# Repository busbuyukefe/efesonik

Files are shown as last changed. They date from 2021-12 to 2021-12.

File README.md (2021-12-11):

# efesonik (v2)

A directional soundbar proof-of-concept using cheap 40kHz transducers.

This project can work with the code from [gururise](https://github.com/gururise/directional_speaker) and uses the STM32-bluepill library of [yet-another-average-joe](https://github.com/yet-another-average-joe/Kicad-STM32)

On the [PDF](https://github.com/busbuyukefe/efesonik/blob/main/Parametrik%20Hoparl%C3%B6r.pdf) you can find my notes about the price, working principle and things like layout of the transducers I took while planning/designing the project.

This system has a set of parametric-speaker arranged side-by-side with independent angle control for each one. This allows the system to be focused on more than one targets thus making a more usable. With each section being able to rotate independently it takes less space with the rotating-mechanism than a single speaker with a gimbal.

You can see the code I used in this [gist](https://gist.github.com/busbuyukefe/7ff0d10a8e1e2d5ed5e22a36067409bf) I posted quite a while ago (Which is essentialy the same code from gururise but with a different pinout)

In the amp section of the block diagram you can use anything else to handle the switching. 
The KiCAD drawing has a single sided PCB design but I didn't had the time to check if it is working.

## I sold this project to someone around March of 2021 so I no longer have it.

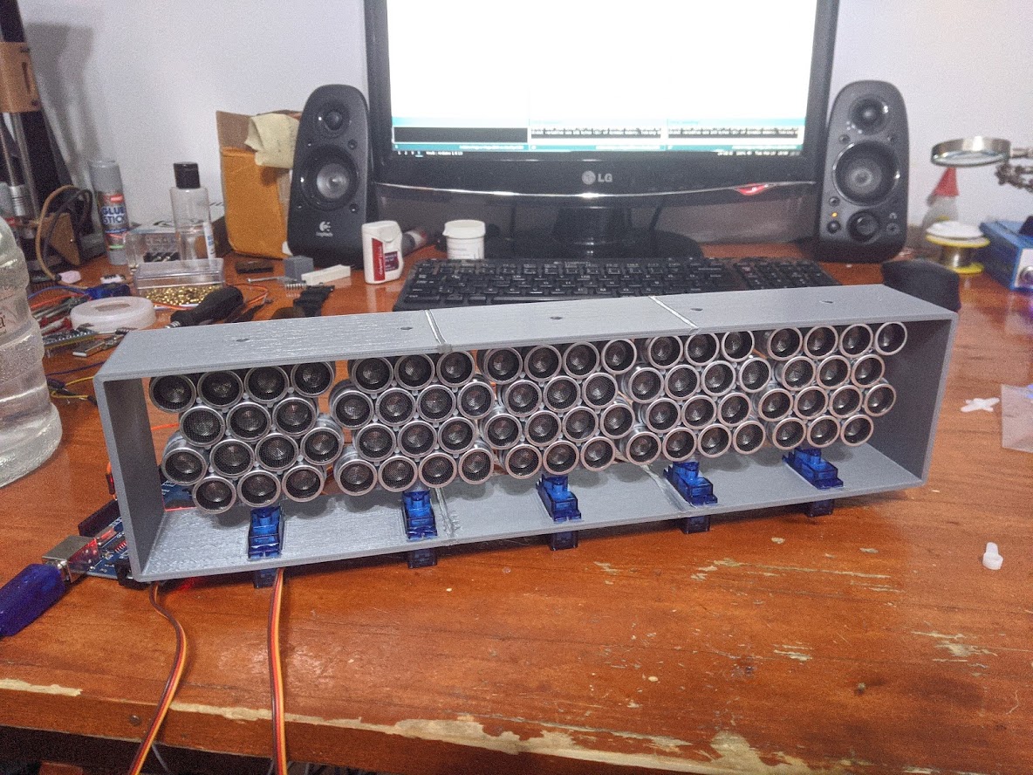
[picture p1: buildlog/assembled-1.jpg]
Assembled Project

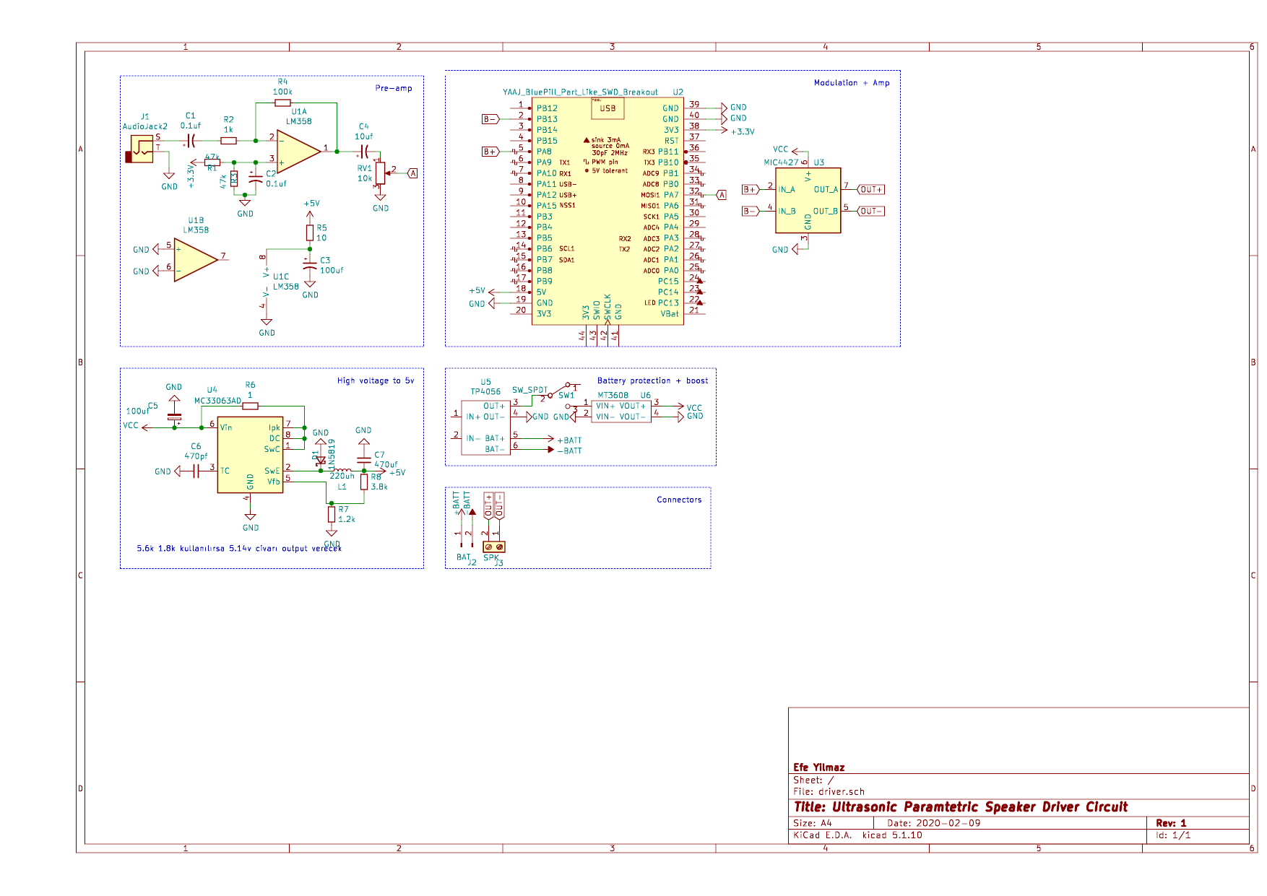
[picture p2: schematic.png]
Schematic of the driver


Video of the first test with the STM32 driver using an old parametric array I built:
first test (https://www.youtube.com/watch?v=-BTZwW2fiP0)

Some photos I took during building it:

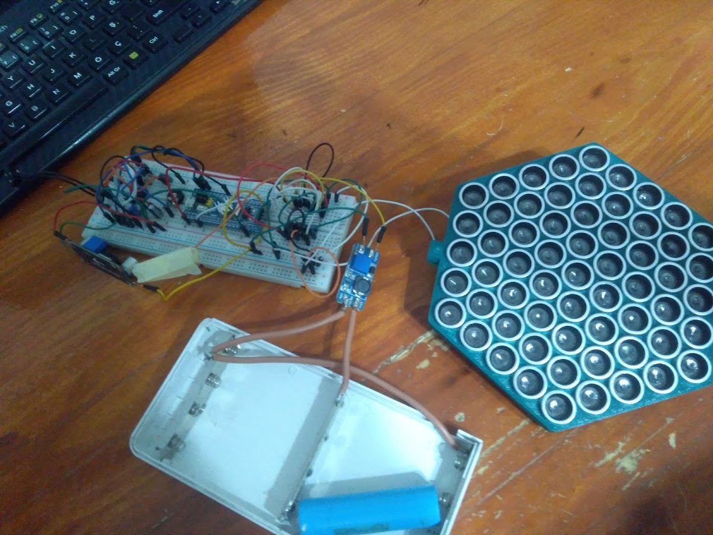
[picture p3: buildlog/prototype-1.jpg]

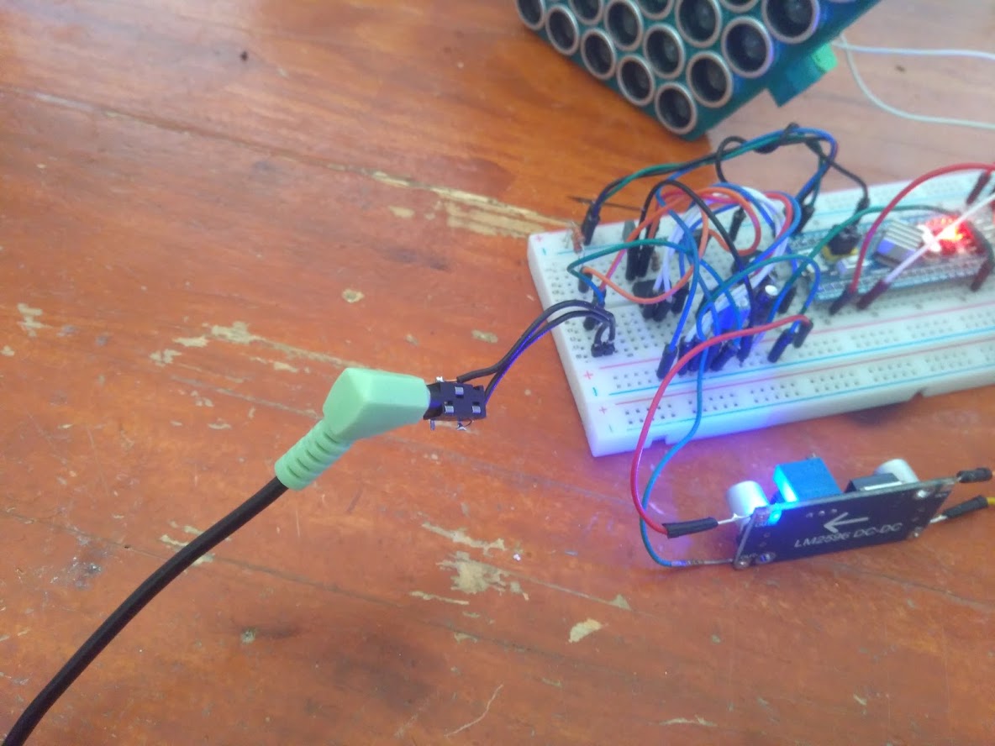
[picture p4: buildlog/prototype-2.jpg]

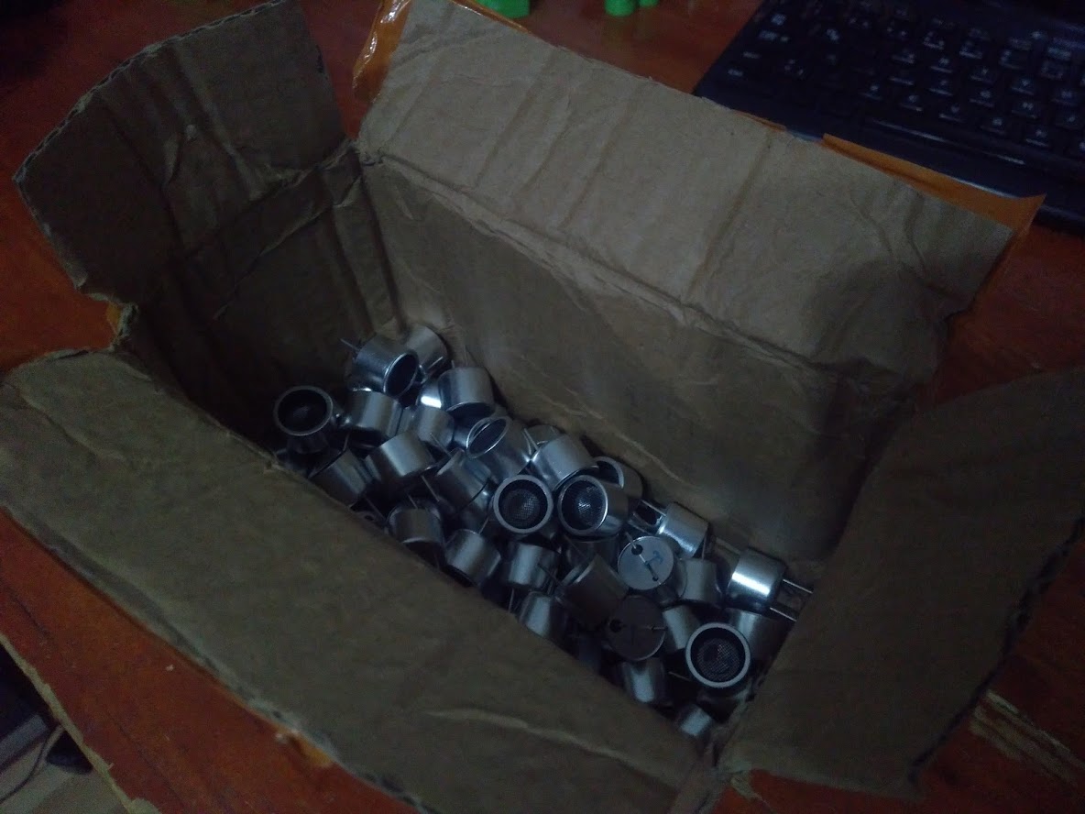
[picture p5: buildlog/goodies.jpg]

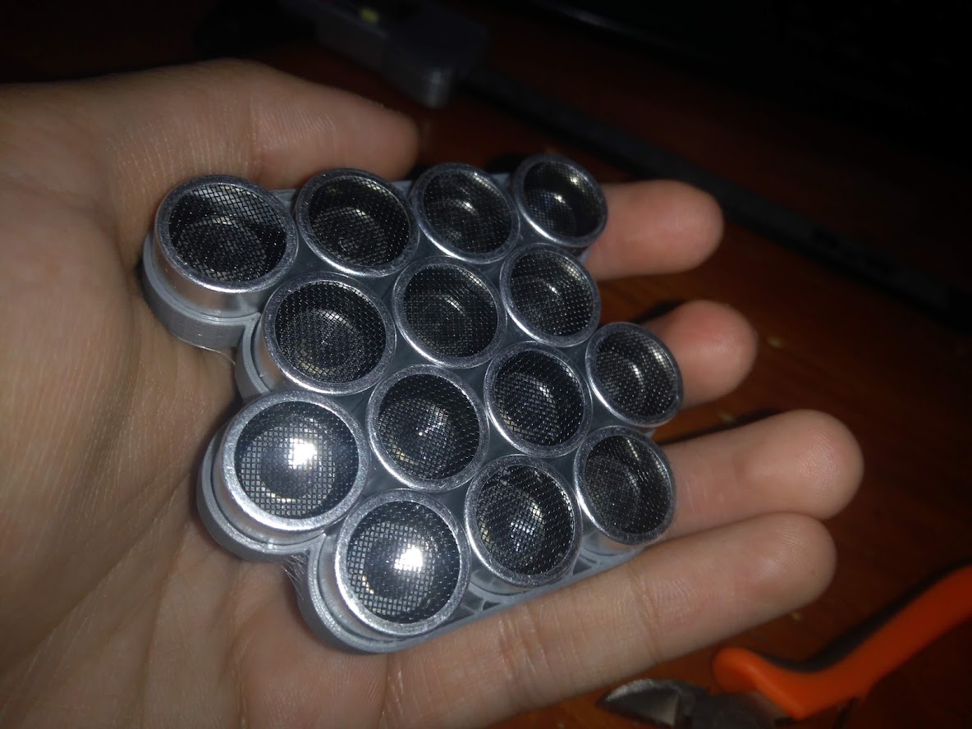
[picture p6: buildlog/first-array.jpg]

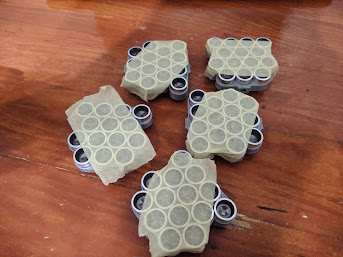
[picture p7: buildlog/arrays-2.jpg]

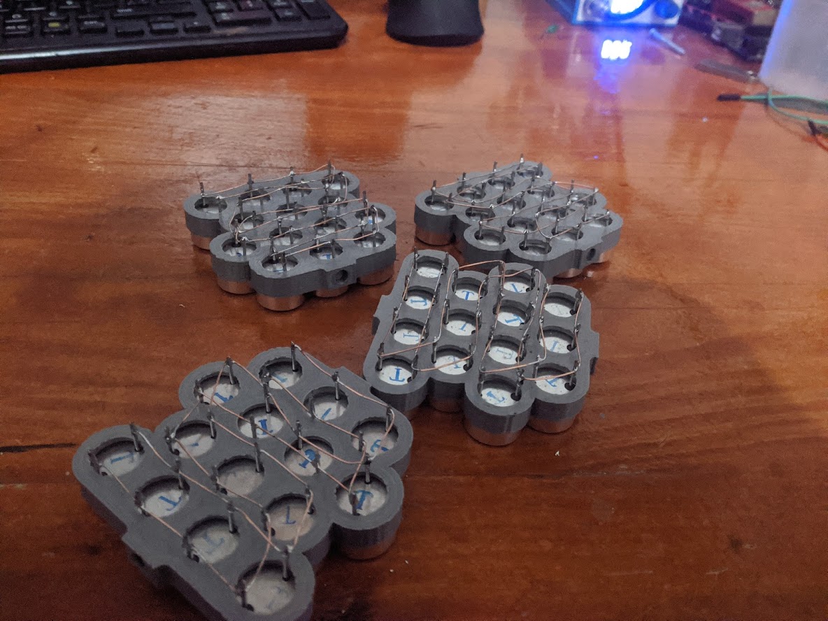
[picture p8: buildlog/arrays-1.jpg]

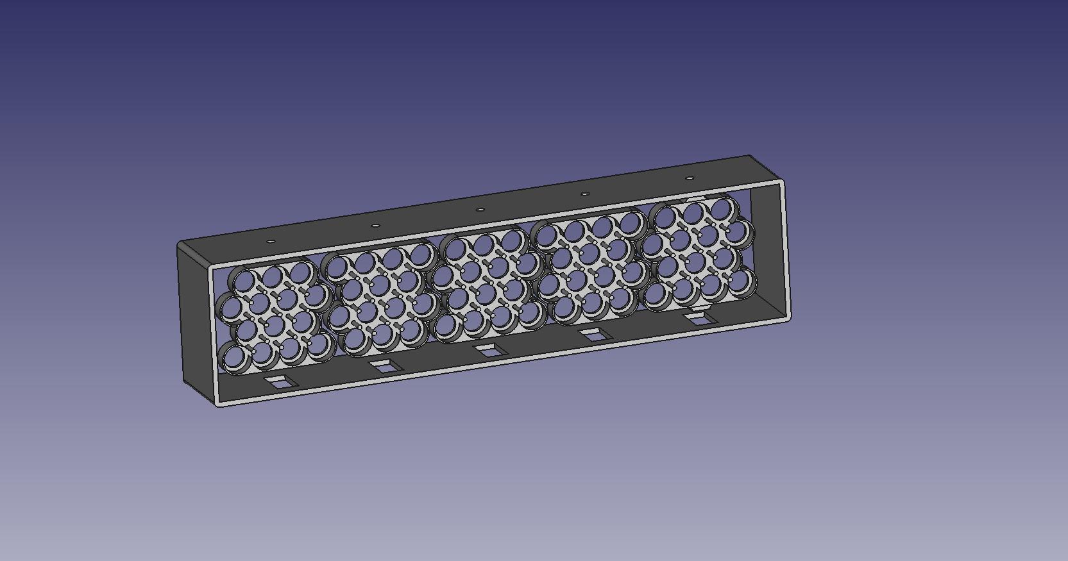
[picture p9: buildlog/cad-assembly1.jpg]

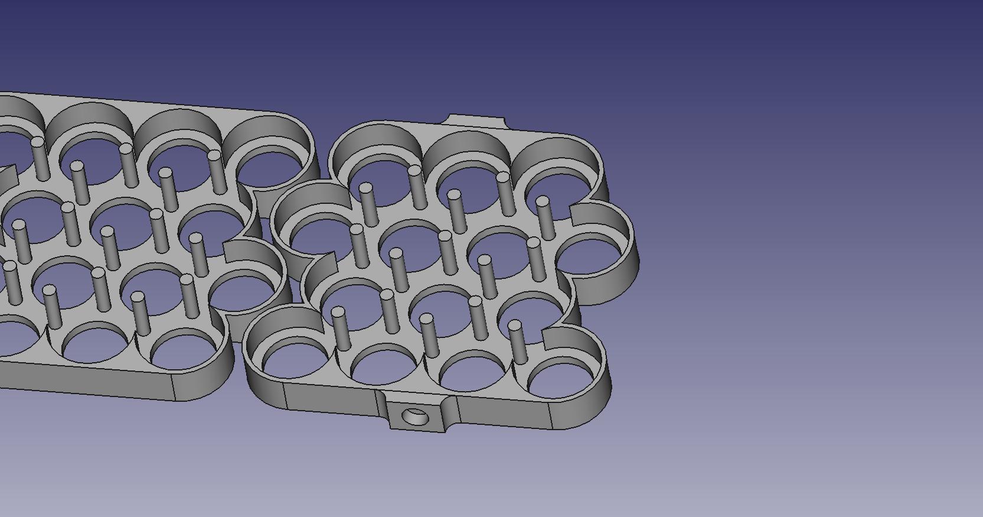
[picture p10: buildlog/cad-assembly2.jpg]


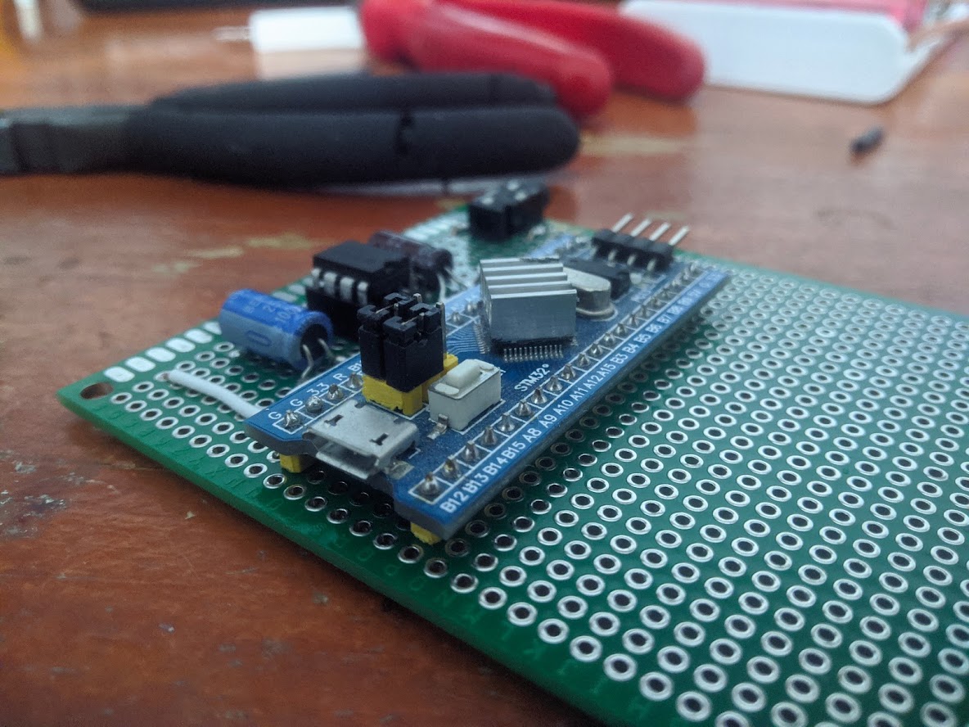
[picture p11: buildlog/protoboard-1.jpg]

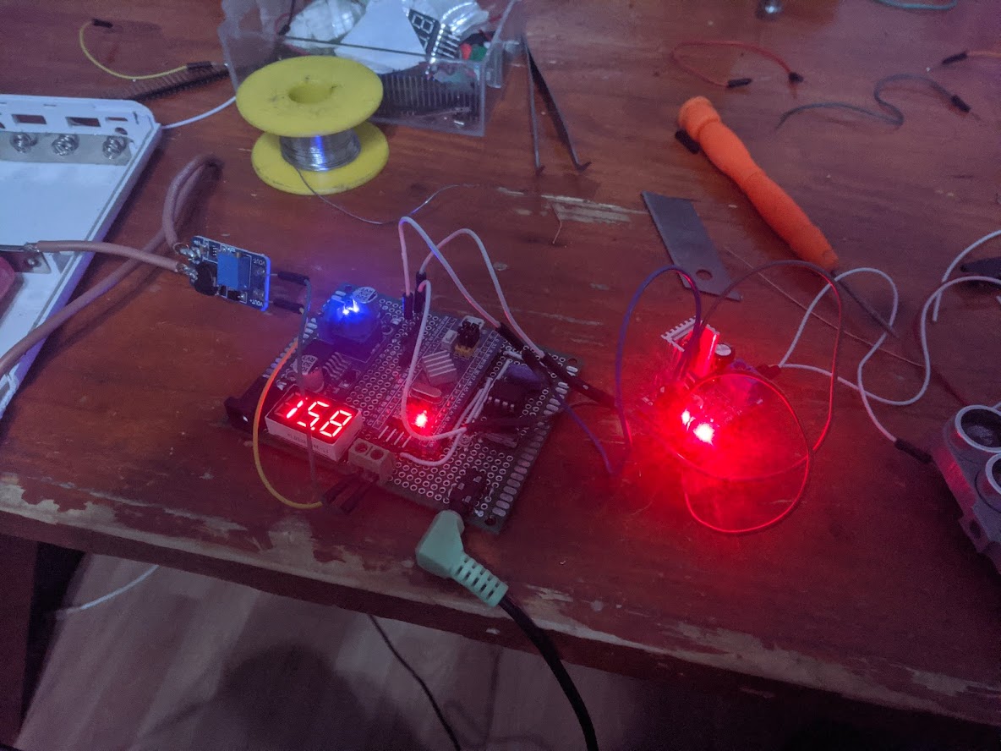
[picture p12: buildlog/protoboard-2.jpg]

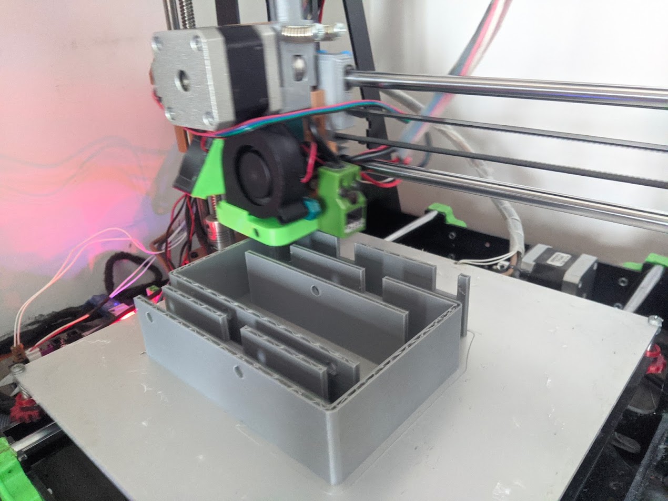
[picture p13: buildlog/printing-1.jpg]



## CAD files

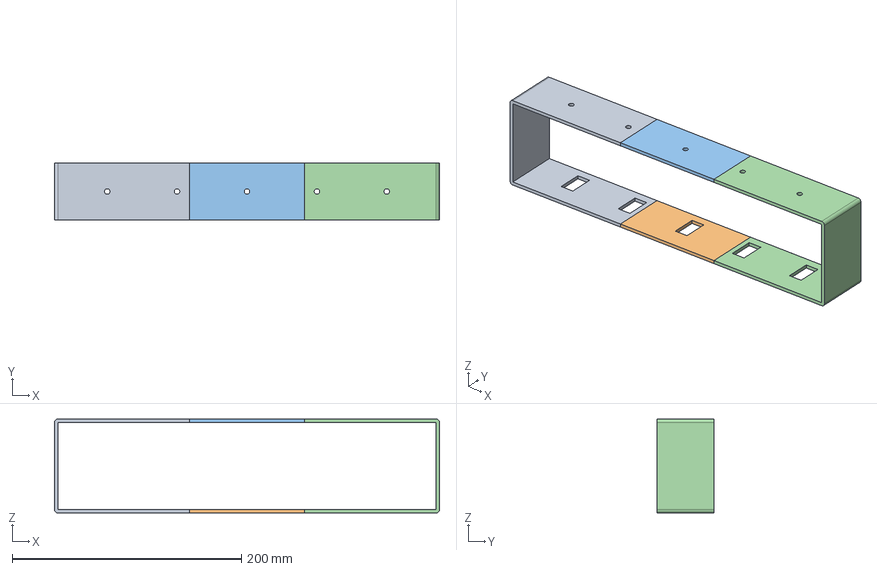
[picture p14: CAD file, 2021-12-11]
3d/frame.FCStd
336.0 x 50.0 x 82.0 mm
Slice.0
Slice.1
Slice.2
Slice.3

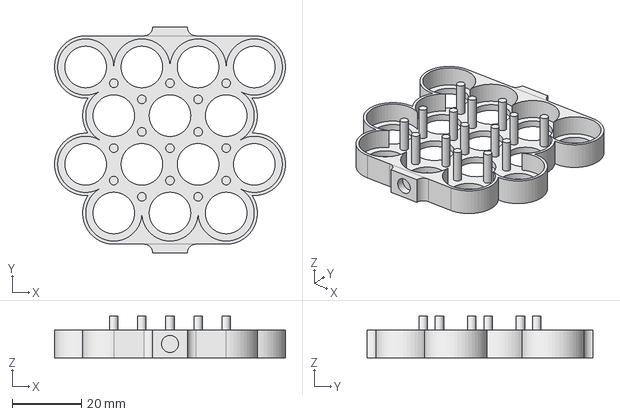
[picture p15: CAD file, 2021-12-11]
3d/test.FCStd
66.6 x 65.1 x 12.0 mm

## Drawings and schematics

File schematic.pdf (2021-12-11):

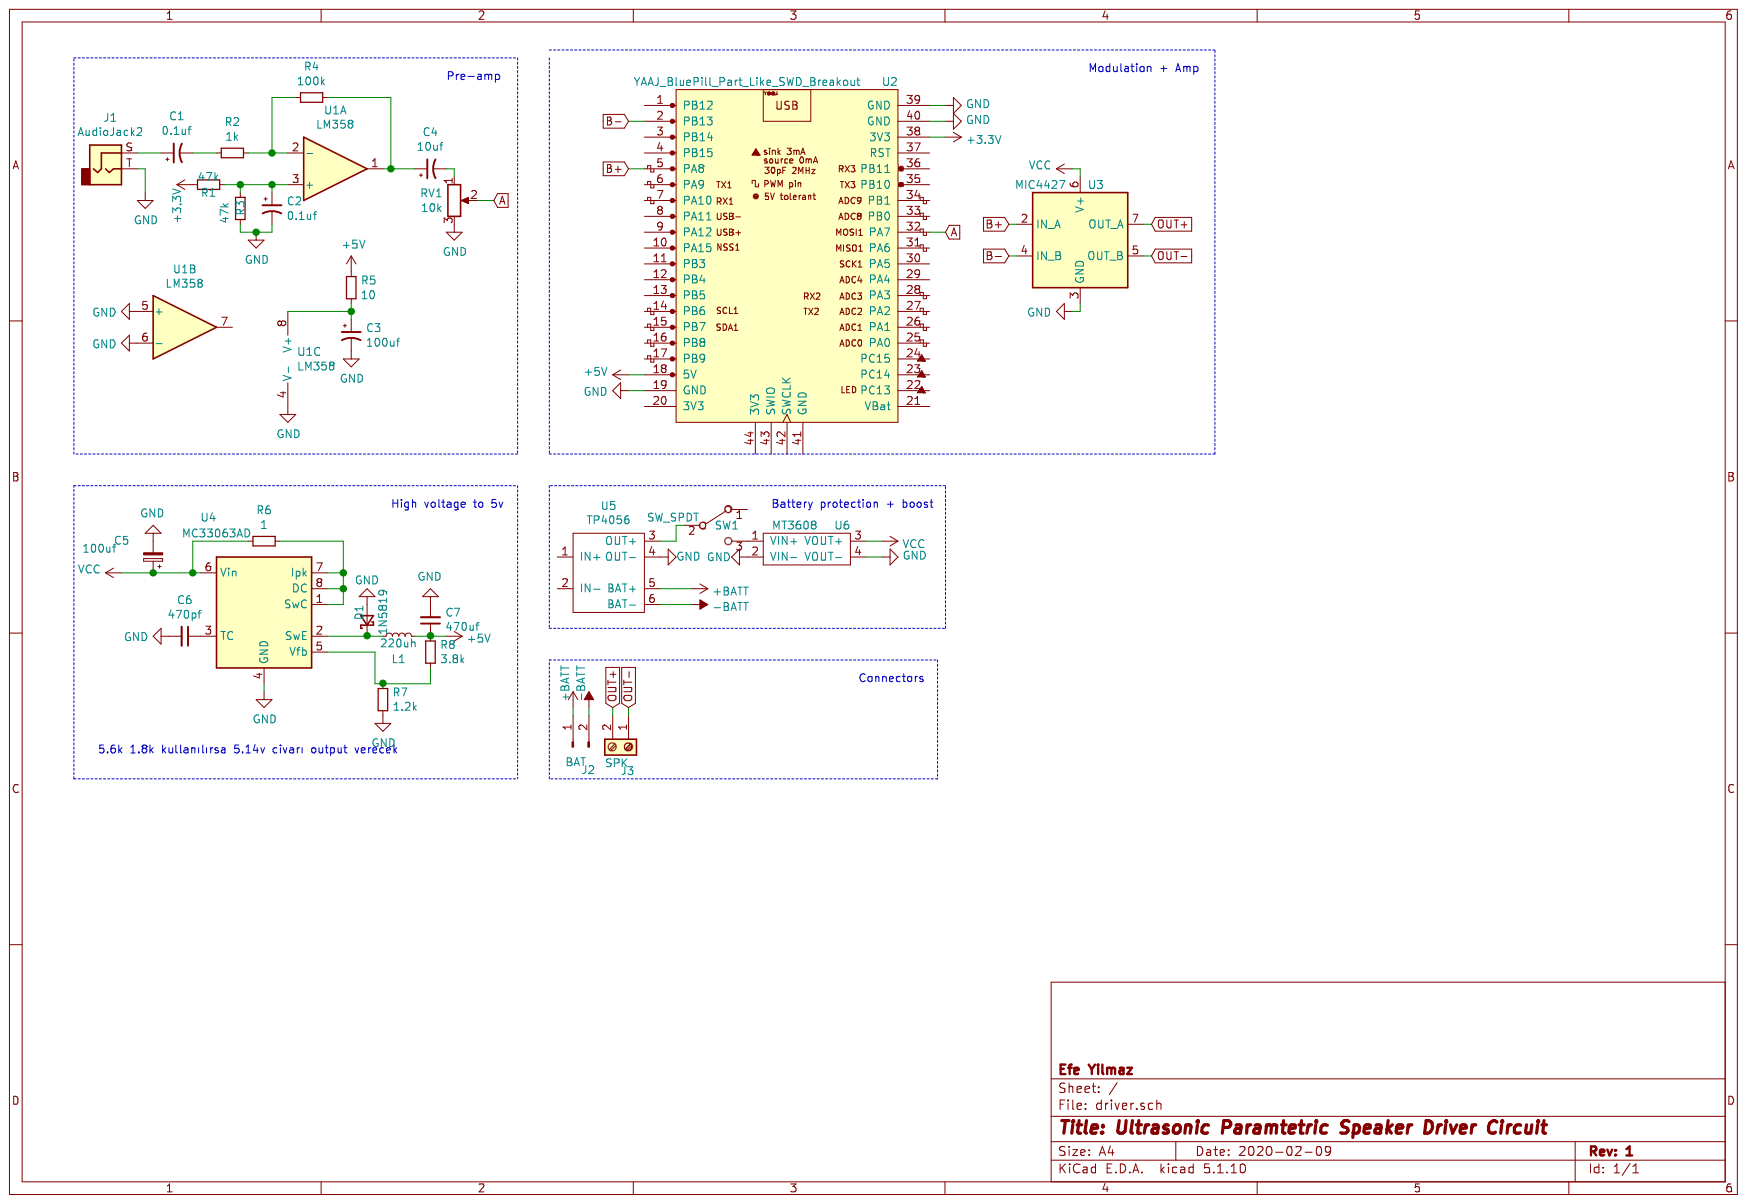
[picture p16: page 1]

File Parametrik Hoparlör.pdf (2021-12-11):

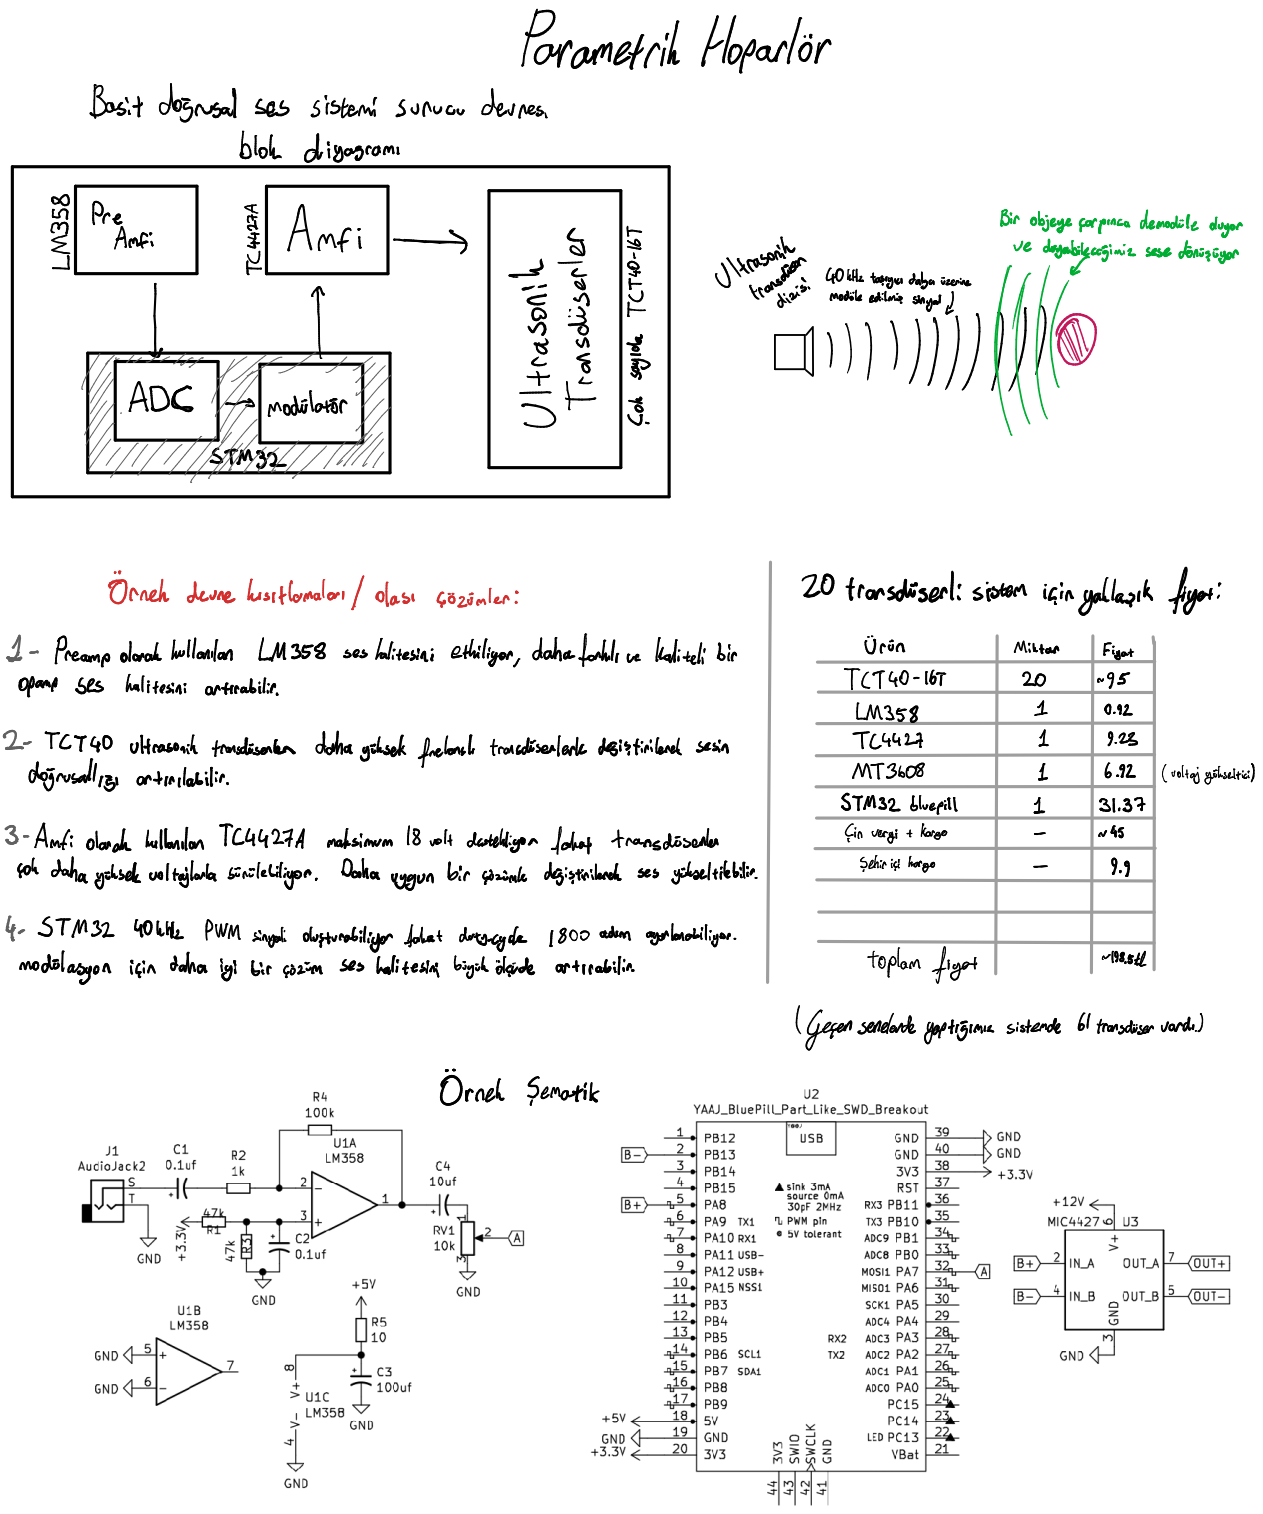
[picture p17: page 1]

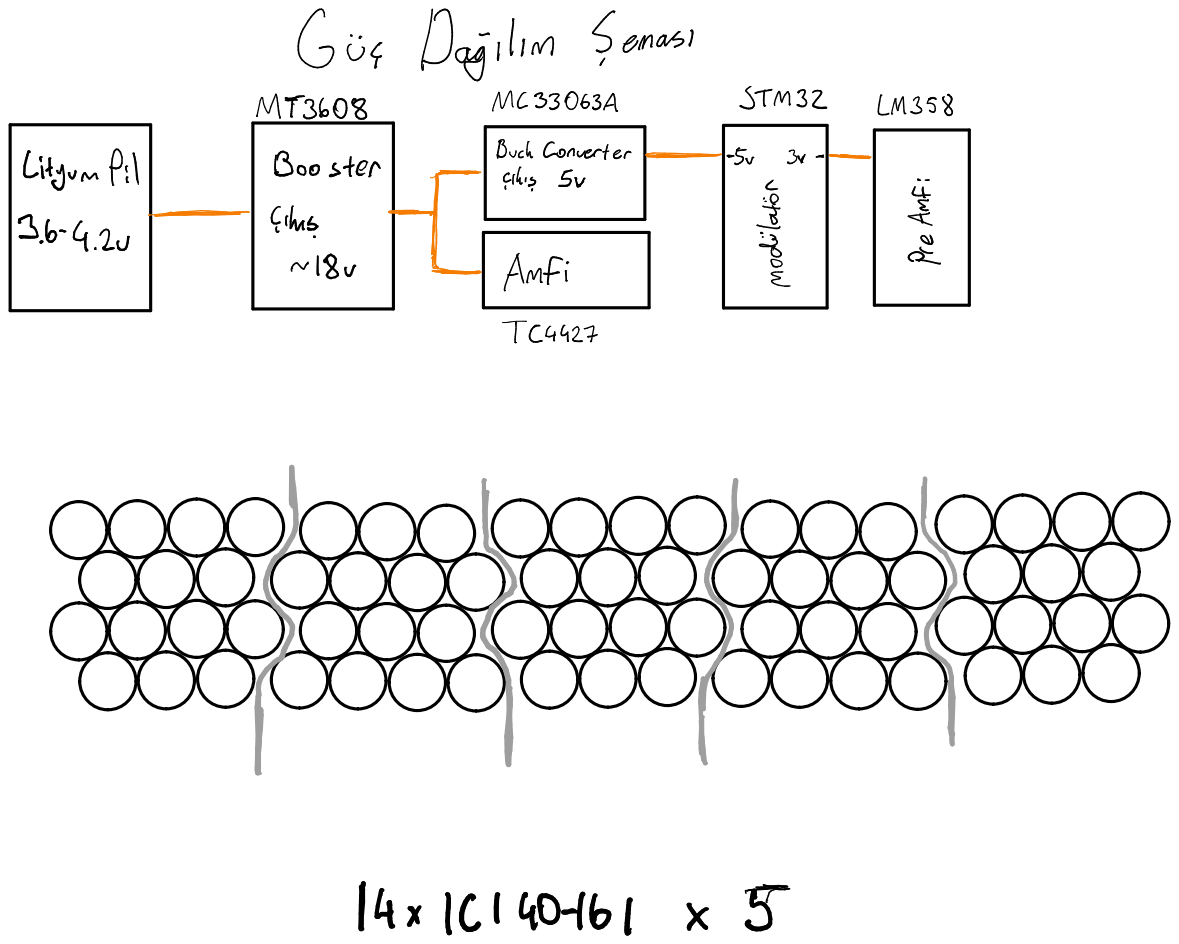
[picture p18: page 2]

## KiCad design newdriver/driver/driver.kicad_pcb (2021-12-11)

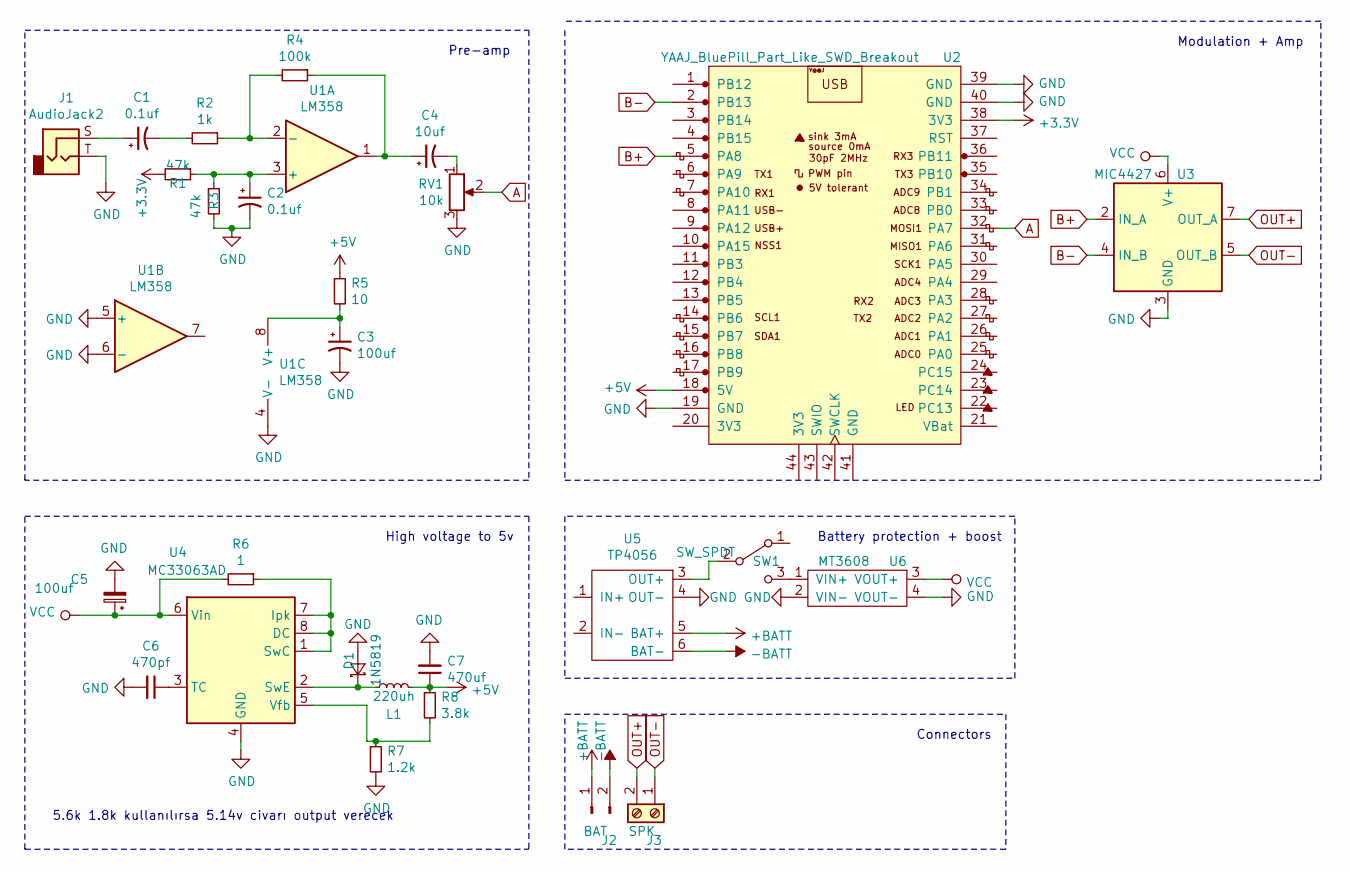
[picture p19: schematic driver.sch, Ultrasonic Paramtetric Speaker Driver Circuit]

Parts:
C1, C2: 0.1uf; C_1206_3216Metric
C3, C5: 100uf; C_1206_3216Metric
C4: 10uf; C_1206_3216Metric
C6: 470pf; C_1206_3216Metric
C7: 470uf; C_1206_3216Metric
D1: 1N5819; D_SMA
J1: AudioJack2; PJ-320B
J2: BAT; PinSocket_1x02_P2.54mm_Vertical
J3: SPK; TerminalBlock_bornier-2_P5.08mm
L1: 220uh; L_12x12mm_H4.5mm
R1, R3: 47k; R_1206_3216Metric
R2: 1k; R_1206_3216Metric
R4: 100k; R_1206_3216Metric
R5: 10; R_1206_3216Metric
R6: 1; R_1206_3216Metric
R7: 1.2k; R_1206_3216Metric
R8: 3.8k; R_1206_3216Metric
RV1: 10k; Potentiometer_Bourns_3314G_Vertical
SW1: SW_SPDT; PinSocket_1x03_P2.54mm_Vertical
U1: LM358; SOIC-8_3.9x4.9mm_P1.27mm
U2: YAAJ_BluePill_Part_Like_SWD_Breakout; YAAJ_BluePill_2
U3: MIC4427; SOIC-8_3.9x4.9mm_P1.27mm
U4: MC33063AD; SOIC-8_3.9x4.9mm_P1.27mm
U5: TP4056
U6: MT3608

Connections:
+3V3: R1.2, U2.38 (3V3)
+5V: C7.1, L1.2, R5.1, R8.1, U2.18 (5V)
+BATT: J2.1, U5.5 (BAT+)
-BATT: J2.2, U5.6 (BAT-)
A: RV1.2, U2.32 (PA7)
B+: U2.5 (PA8), U3.2 (IN_A)
B-: U2.2 (PB13), U3.4 (IN_B)
GND: C2.2, C3.2, C5.2, C6.2, C7.2, D1.2 (A), J1.T, R3.2, R7.2, RV1.3, U1.4 (V-), U1.5 (+), U1.6 (-), U2.19 (GND), U2.39 (GND), U2.40 (GND), U3.3 (GND), U4.4 (GND), U5.4 (OUT-), U6.2 (VIN-), U6.4 (VOUT-)
unnamed: C1.1, J1.S
unnamed: C1.2, R2.2
unnamed: C2.1, R1.1, R3.1, U1.3 (+)
unnamed: C3.1, R5.2, U1.8 (V+)
unnamed: C4.1, R4.1, U1.1
unnamed: C4.2, RV1.1
unnamed: C6.1, U4.3 (TC)
unnamed: D1.1 (K), L1.1, U4.2 (SwE)
unnamed: R2.1, R4.2, U1.2 (-)
unnamed: R6.1, U4.1 (SwC), U4.7 (Ipk), U4.8 (DC)
unnamed: R7.1, R8.2, U4.5 (Vfb)
unnamed: SW1.2 (B), U5.3 (OUT+)
unnamed: SW1.3 (C), U6.1 (VIN+)
OUT+: J3.2, U3.7 (OUT_A)
OUT-: J3.1, U3.5 (OUT_B)
VCC: C5.1, R6.2, U3.6 (V+), U4.6 (Vin), U6.3 (VOUT+)

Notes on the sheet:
High voltage to 5v
Pre-amp
Modulation + Amp
Battery protection + boost
Connectors
5.6k 1.8k kullanılırsa 5.14v civarı output verecek

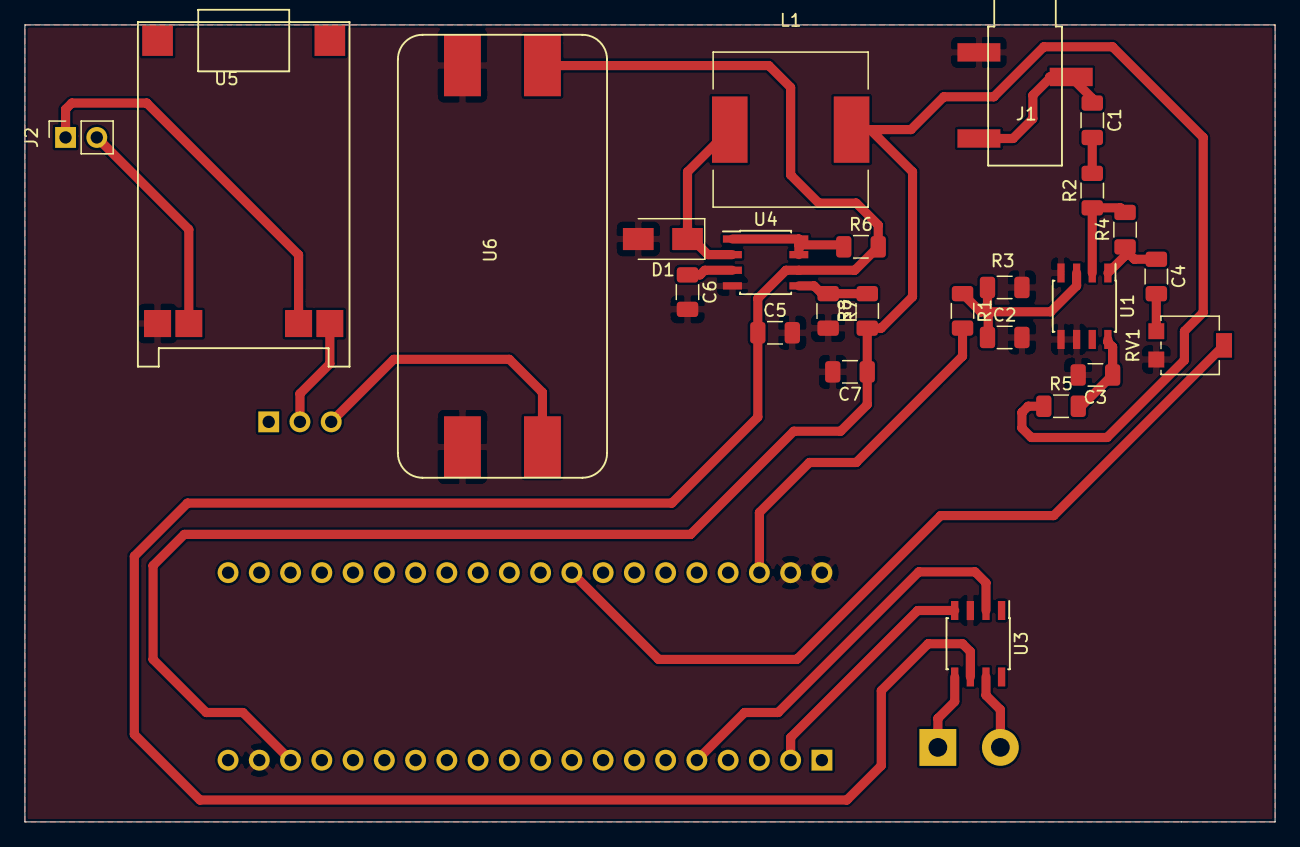
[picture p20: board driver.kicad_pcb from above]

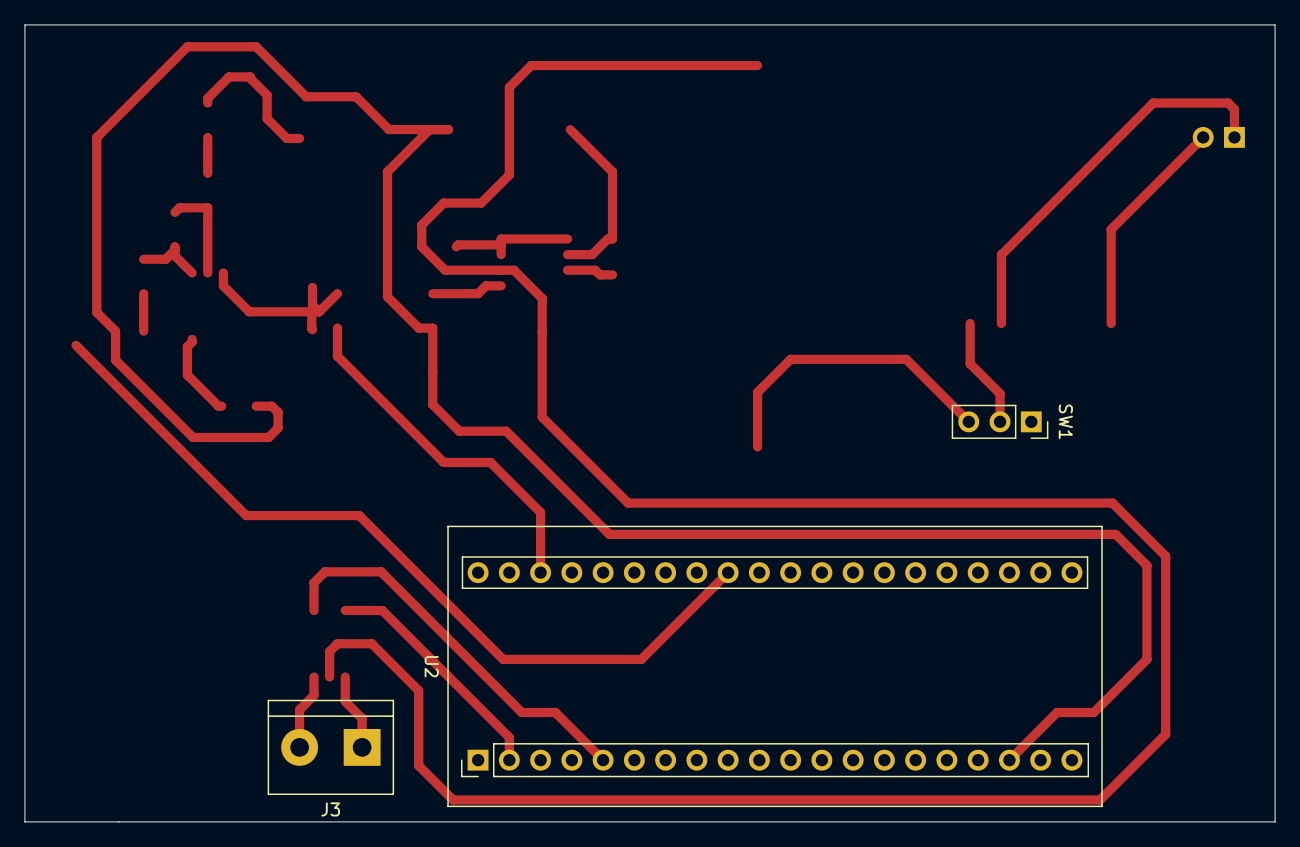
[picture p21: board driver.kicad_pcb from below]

Board: 2 copper layers, 101.6 x 64.8 mm, 28 parts (3 on the bottom side), 24 nets.

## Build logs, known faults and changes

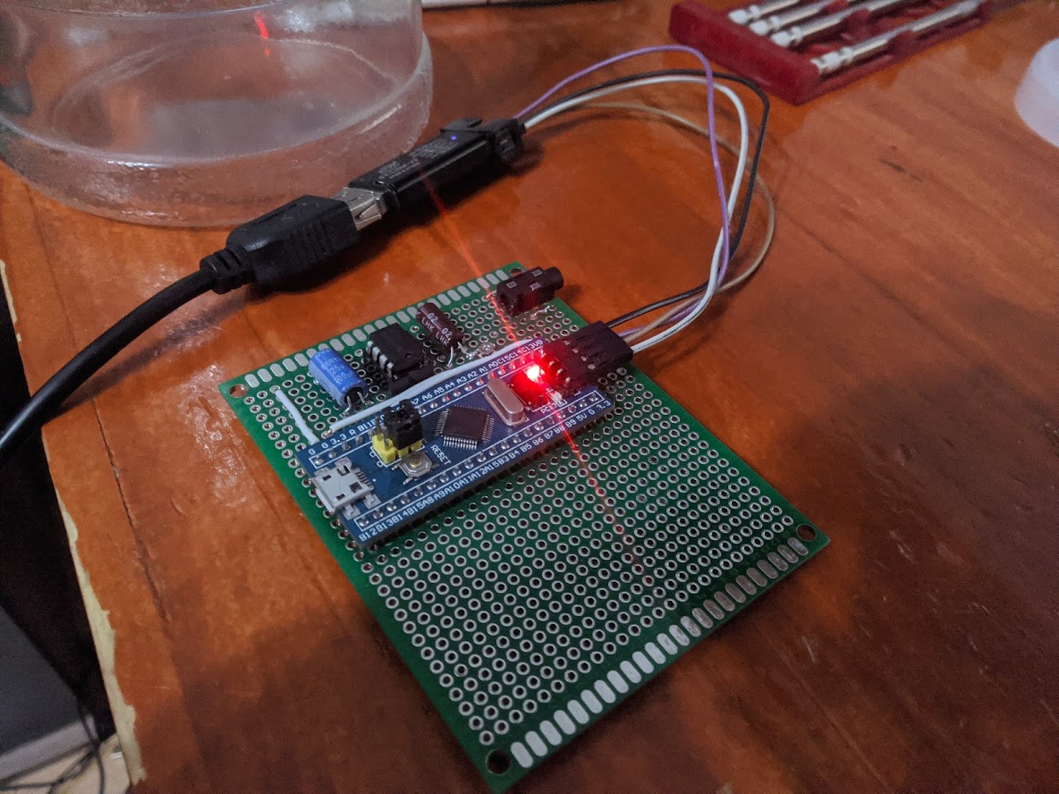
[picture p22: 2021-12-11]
buildlog/programming-1.jpg

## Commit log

2021-12-11 First dump of old files
    [driver.kicad_pcb, driver.sch, frame.FCStd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]
2021-12-11 Schematics for those don't have KiCAD
2021-12-11 Added schematic to README
2021-12-11 Assembly like preview from FreeCAD
